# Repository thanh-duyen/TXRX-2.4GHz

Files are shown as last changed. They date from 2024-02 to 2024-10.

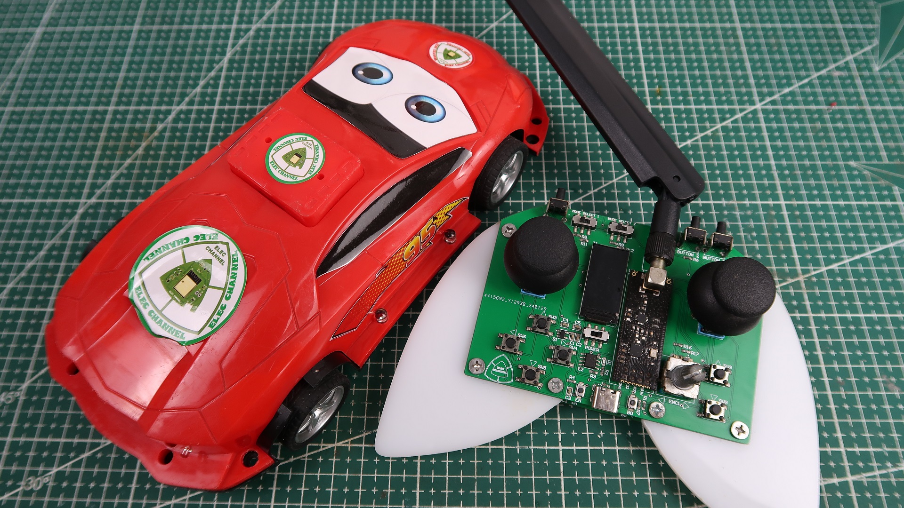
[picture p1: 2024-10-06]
RX_V3_Image_1.JPG

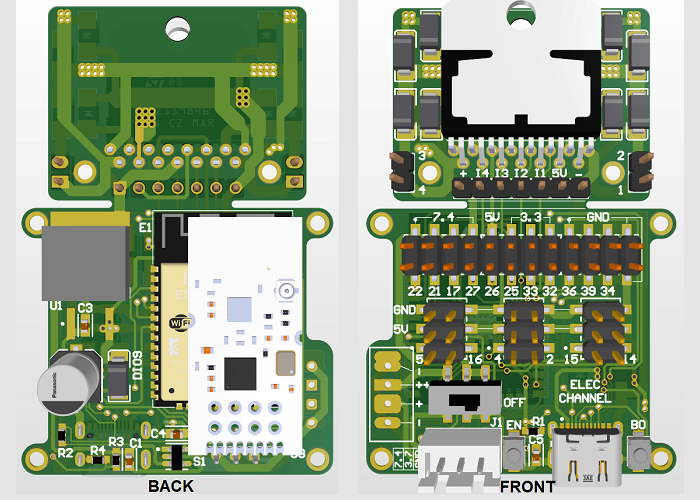
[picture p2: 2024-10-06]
RX_V3_Image_2.png

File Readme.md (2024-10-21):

The reciver for testing is reused from here: https://www.youtube.com/watch?v=fhfw287tRes&t=444s
List of components for TX circuit:
1. Button 3x4mm 2 Pins x2
2. 18650 holder smd x1
3. Button FP-1825027-8-MFG x3
4. Capacitor 0.1uF 0603 x3
5. Capacitor 10uF 0603 x2
6. LED 0603 x1
7. ESP32_WROOM x1
8. ENCODER 24 PPR x1
9. USB Type-C 12 Pins x1
10. JoyStick PS5 x2
11. Switch 6 Pins SMD x3
12. Resistor 100K 0603 x10
13. Resistor 1K 0603 x1
14. Resistor 1K2 0603 x1
15. Resistor 47K 0603 x1
16. Resistor 10K 0603 x1
17. SPX3819M5-L-3-3 x2
18. Button 6x6x6mm 4 Pins x6
19. TFT SPI 13 Pins 80x160 x1
20. nRF24l01 + PA + LNA DIG x1
21. TP4056 x1

List of components for RX circuit version 1:
1. Capacitor 0603 0.1uF x6
2. FP-TAJC-MFG 100uF x1
3. FP-FKD8-MFG 330uF x1
4. LED 0603 x8
5. Diode 1N5819HW x1
6. BUTTON 3x4mm 2 Pin x1
7. USB Type-C 12 Pins x1
8. Inductor 100uH x1
9. Resistor 0603 2K2 x6
10. Resistor 0603 1K x2
11. Resistor 0603 1K2 x1
12. Resistor 0805 180 x1
13. Resistor 0805 0.33 x1
14. Resistor 0603 47K x1
15. Resistor 0603 15K x1
16. Resistor 0603 10k x1
17. SPX3819M5-L-3-3 x1
18. MSS-22D18G2 SWITCH x1
19. TQFP32 ATmega328-AU x1
20. MC34063ACD-TR x1
21. NRF24L01 + PA + LNA SMD x1
22. TP4056 x1
23. Crytal 16MHz 3 Pins x1
24. Led 3mm White x2, Red x2
List of accessories used for RX circuit:
1. Ball-bearings 11.5x10x4(thickness)x3(shaft)mm x2
2. Rubber wheels 18x8x2mm x4
3. Aluminum tube 3(Outer diameter)x2mm
4. Steel/zinc bar 1mm
5. Screw M2, M1.2
6. Servo SG90 360 degree x1
7. 1.5g Micro Linear Servo x1

Note for RX Version 1: The PCB that I designed for using boost to 5V, but the current was not enough to operate, so I removed the ic boost and jumped the direct battery to 5V signal.

For RX version 3, you can get all source here: https://www.pcbway.com/project/shareproject/2_4GHz_receiver_circuit_using_ESP32_nRF24L01_with_IC_motor_controller_L298N_dc1f96e2.html

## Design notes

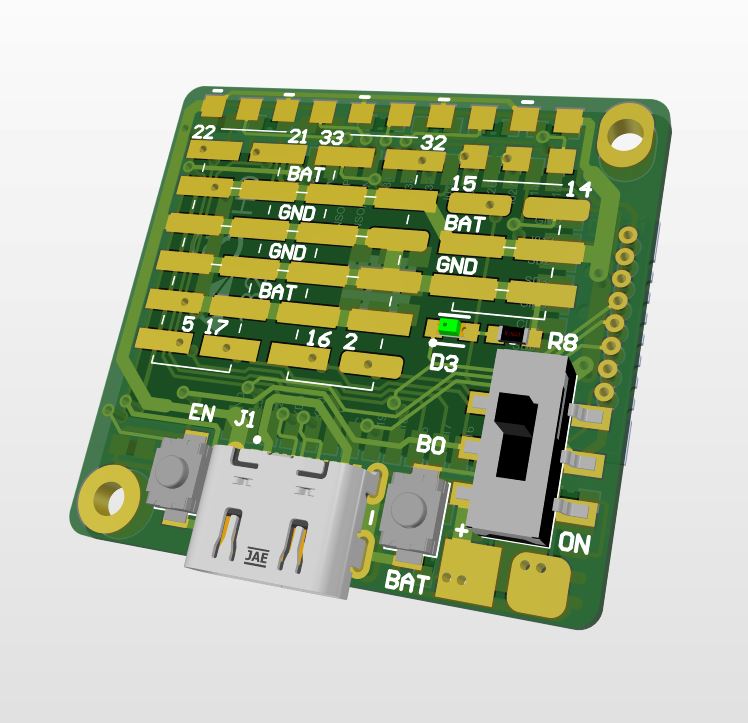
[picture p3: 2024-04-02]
RX_V2_Image_2.JPG

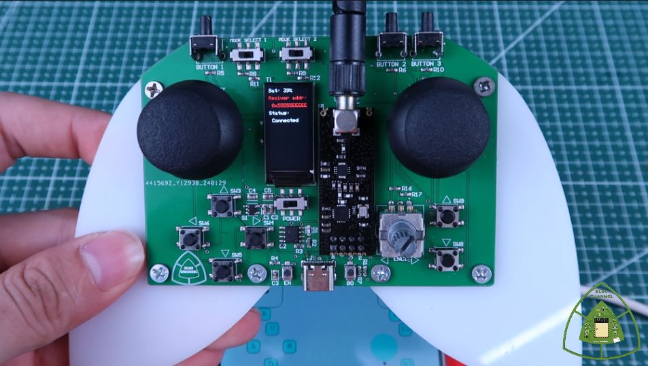
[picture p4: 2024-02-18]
TX_Image.JPG

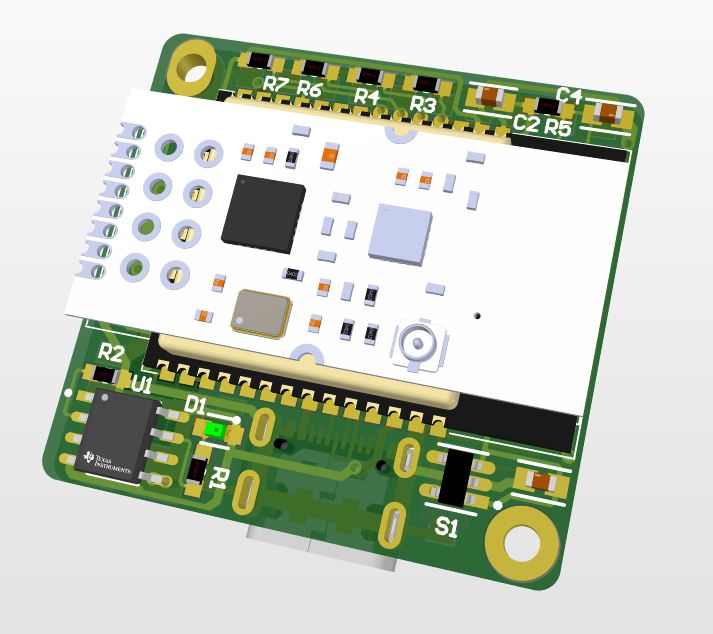
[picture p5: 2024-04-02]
RX_V2_Image_3.JPG

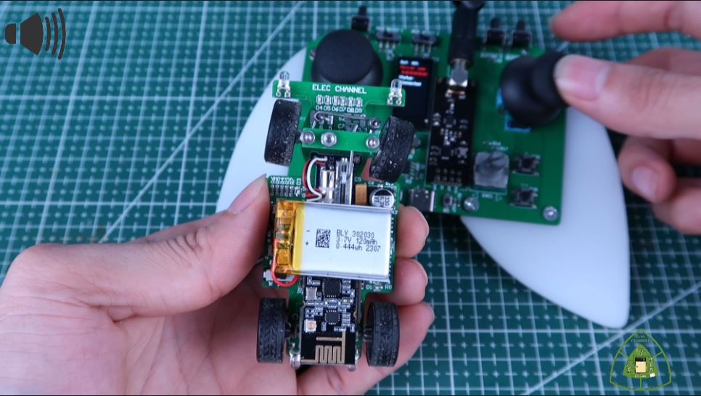
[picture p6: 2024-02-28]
RX_V1_Image.JPG

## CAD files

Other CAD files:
accessory.dwg

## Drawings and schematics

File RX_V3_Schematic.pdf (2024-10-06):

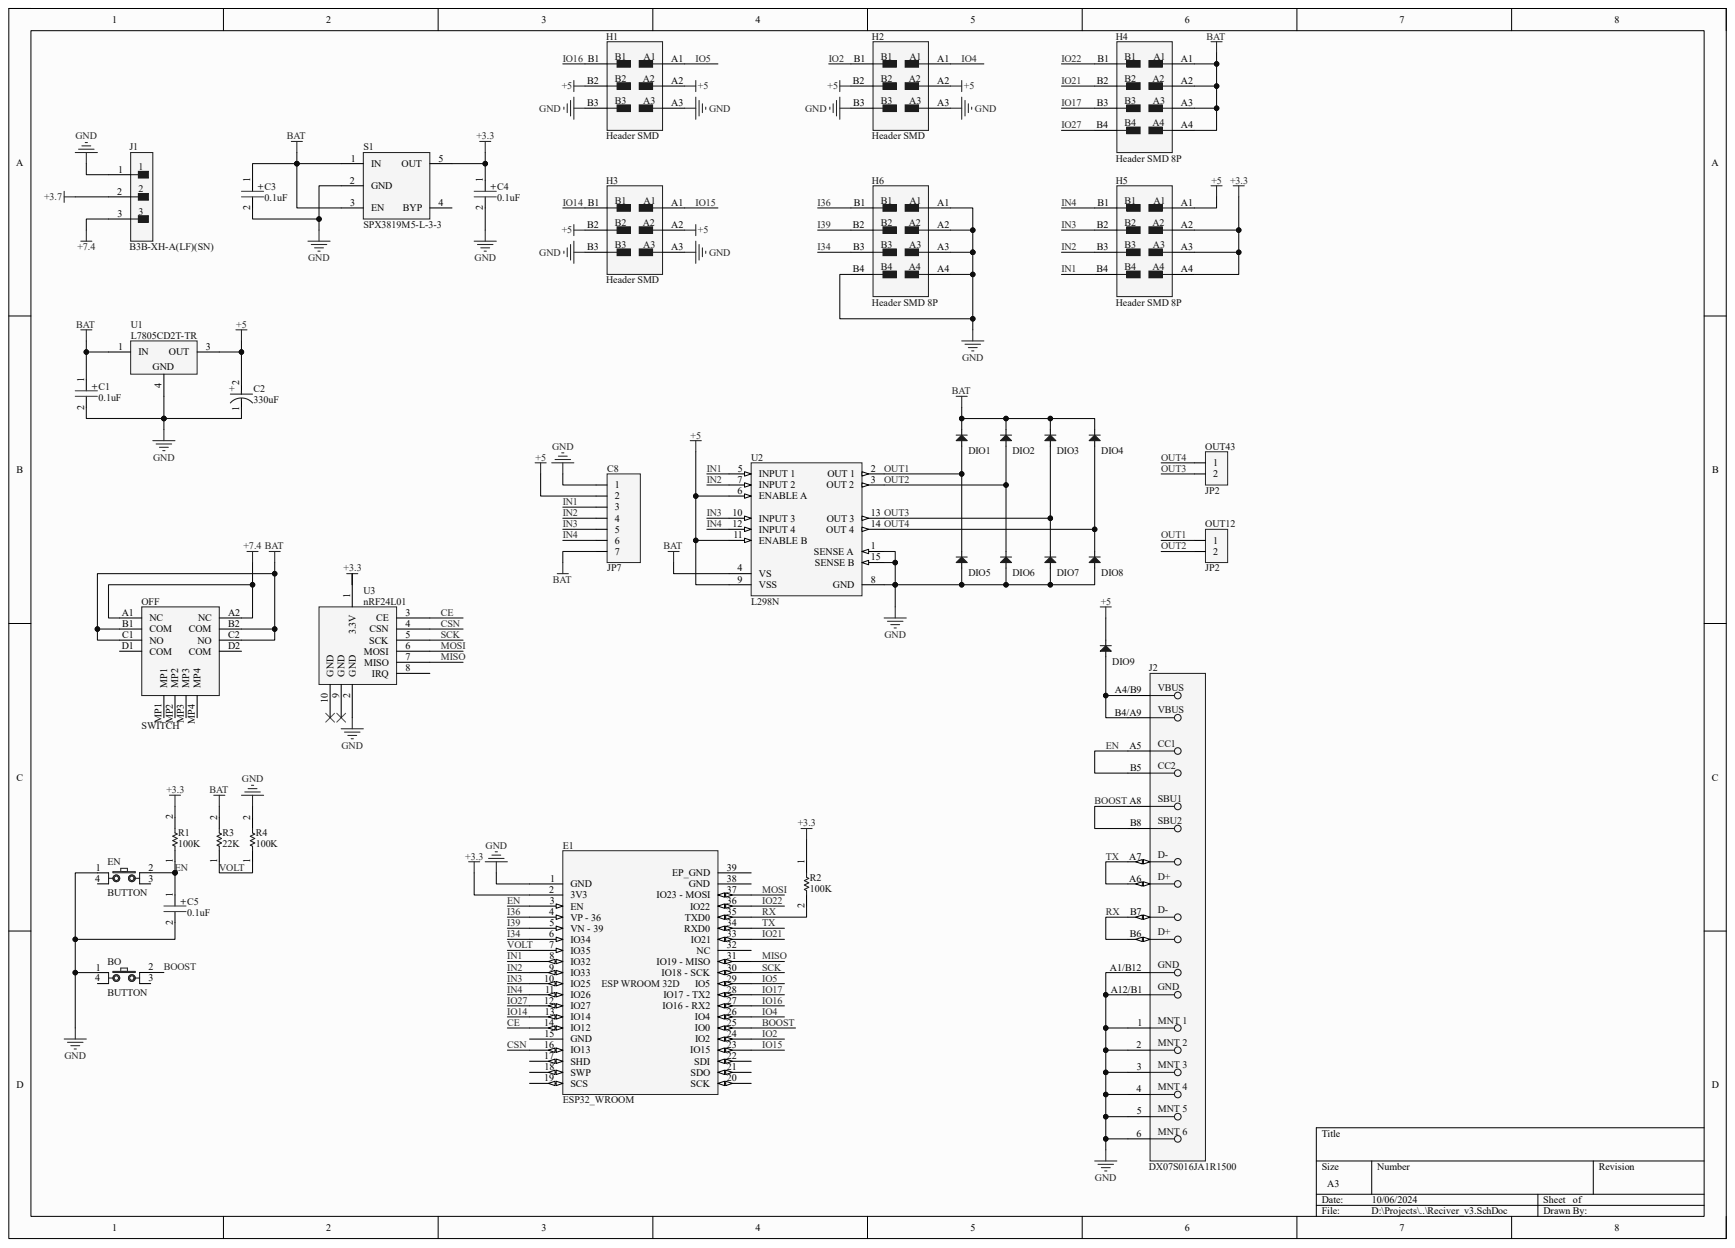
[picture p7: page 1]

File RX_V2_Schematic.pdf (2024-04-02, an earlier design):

+5M 2 1

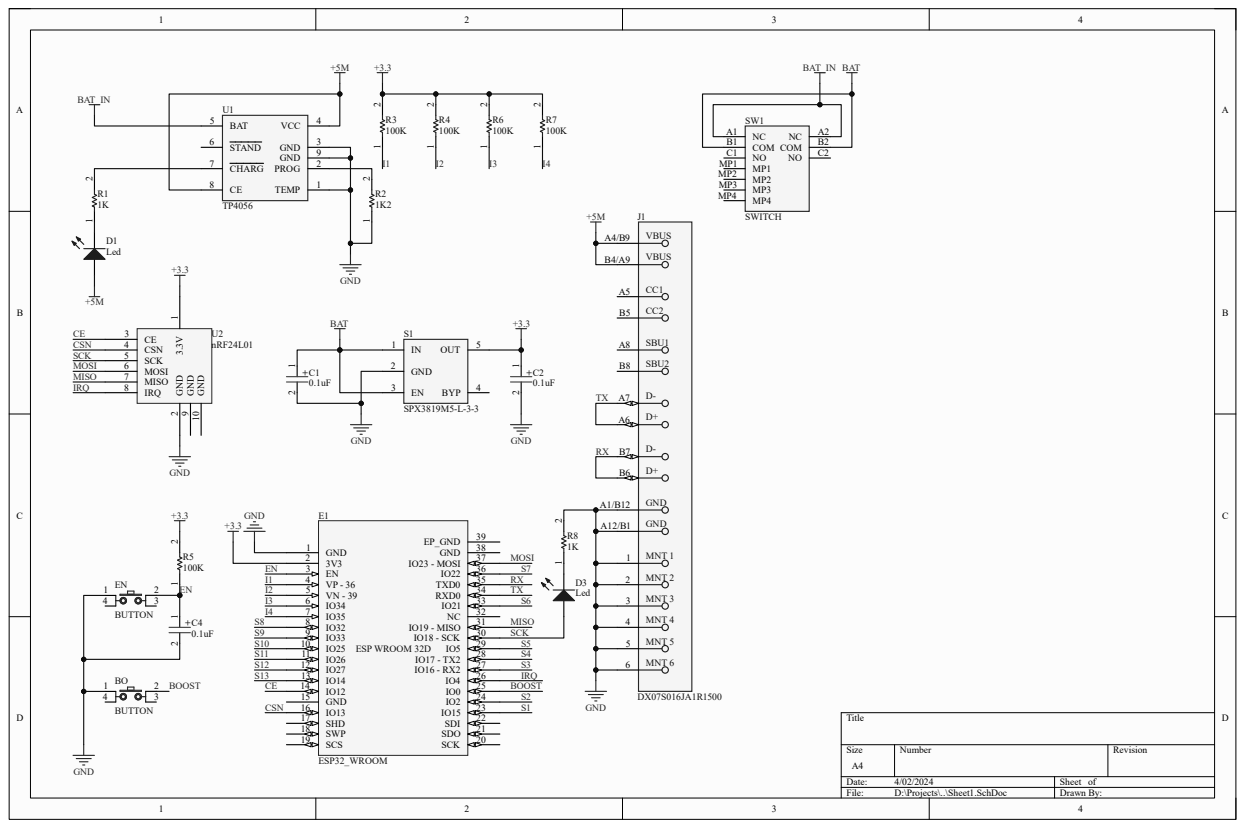
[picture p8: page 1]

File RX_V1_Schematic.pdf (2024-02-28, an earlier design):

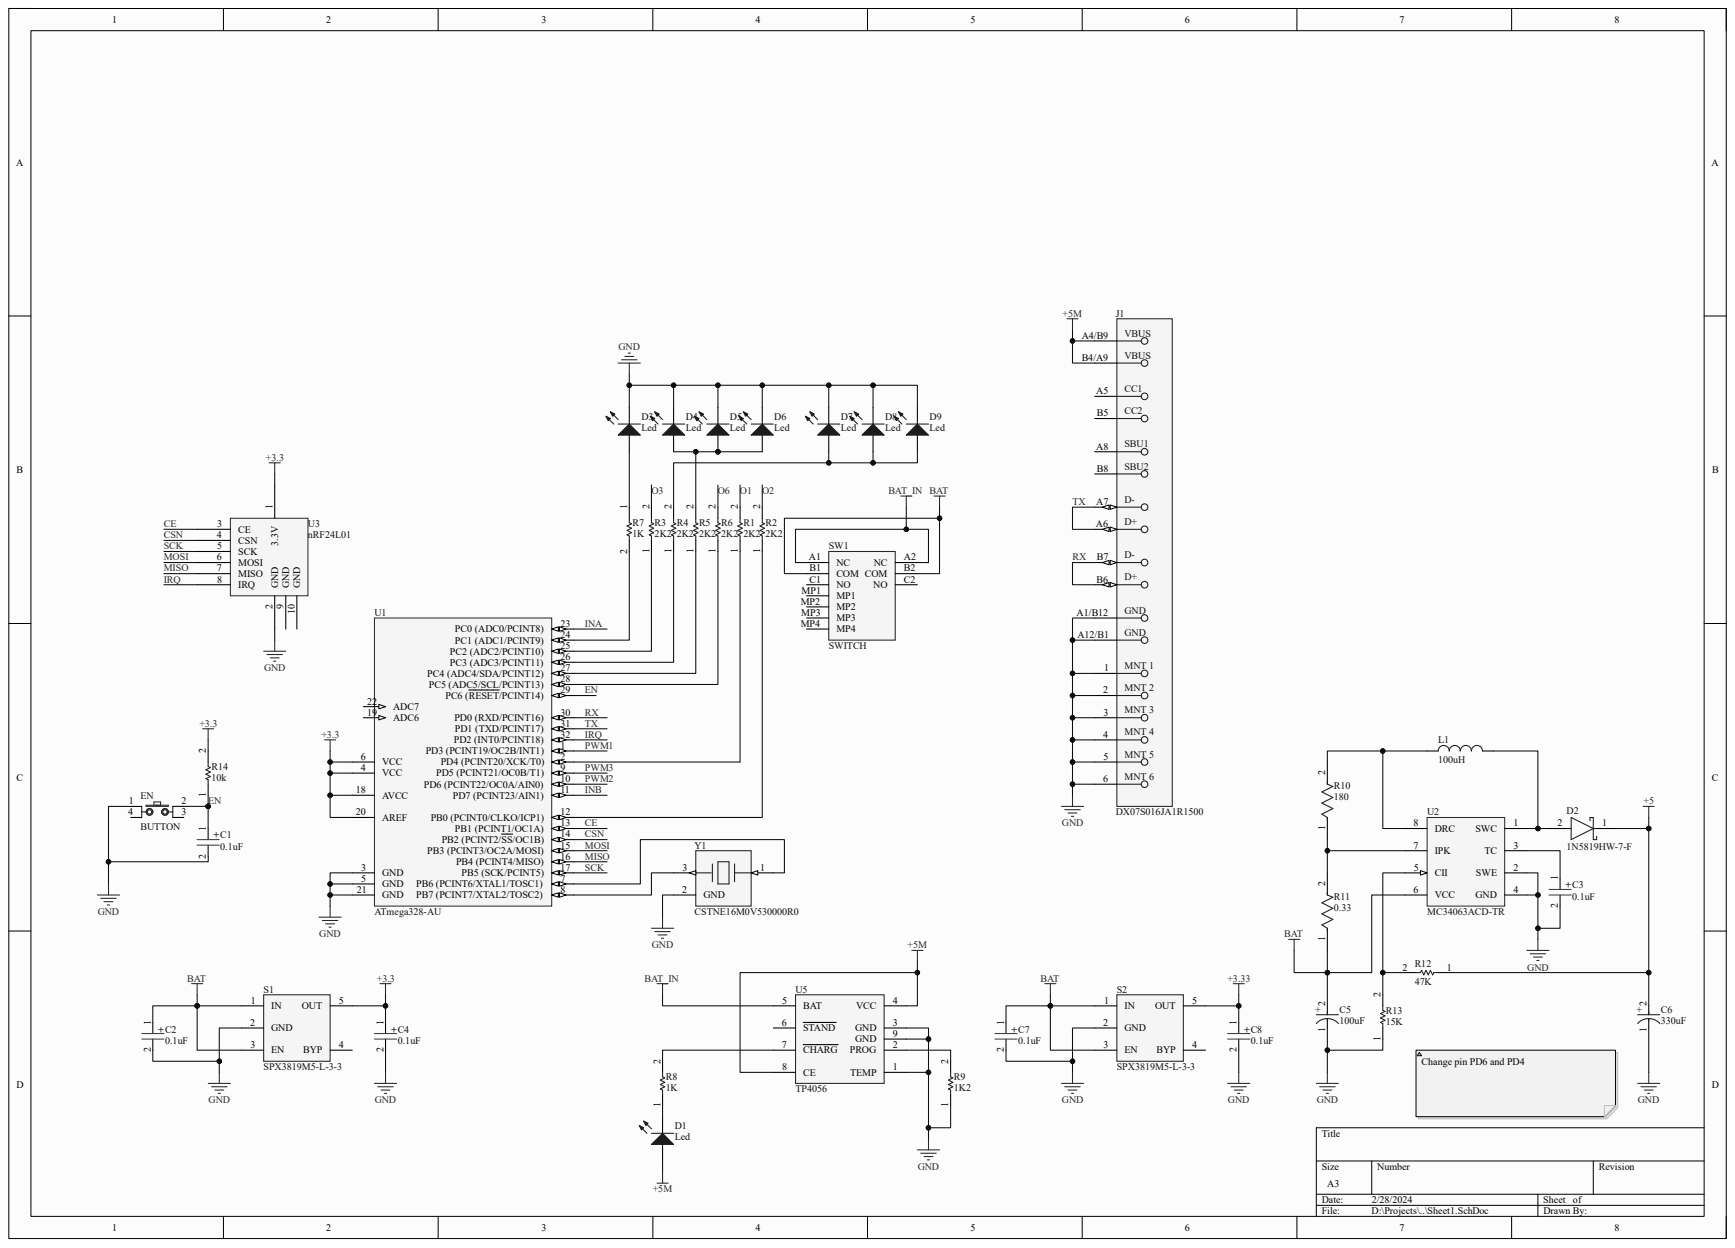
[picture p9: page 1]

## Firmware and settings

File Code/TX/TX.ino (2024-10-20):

#include "data.h"

Adafruit_ST7735 tft = Adafruit_ST7735(CS_LCD_PIN, DC_LCD_PIN, RST_LCD_PIN);
RF24 radio(CE_PIN, CSN_PIN);

void read_battery(bool trigger = false){
  static uint32_t time_readBattery = 0;
  if(trigger) time_readBattery = millis();
  if (time_readBattery > millis())
    return;
  time_readBattery = millis() + 2*MINUTE;
  float volt = read_adc(VOLT_PIN,5)*7.25/4095;
  tft.setCursor(0,0);
  tft.setTextColor(ST77XX_WHITE,ST77XX_BLACK);
  tft.fillRect(0,0,40,15,ST77XX_BLACK);
  
  uint8_t percent = (volt-3.2)*100;
  if(last_batPercent > percent)
    last_batPercent = percent;
  tft.print("Bat: "+String(last_batPercent)+"%");
}
void print_info(){
  String tmp = "";
  for(uint8_t j = 0; j < 5; j++){
    if(EEPROM.read(addnRF_index*5+1+j) < 0x10) tmp += "0";
      tmp += String(EEPROM.read(addnRF_index*5+1+j),HEX);
  }
  tmp.toUpperCase();
  tmp.toCharArray(addnRF_value[addnRF_index],11);
  
  tft.setCursor(0,15);
  tft.setTextColor(ST77XX_RED,ST77XX_BLACK);
  tft.print("ReciverAddr: ");
  tft.setCursor(6,30);
  tft.print("0x"+String(addnRF_value[addnRF_index]));
  tft.setCursor(0,45);
  tft.print("ReciverBa:Unk");
}
void merge_rfdata(sData *data, char *output){
  /* byte 0                      |byte 1  |byte 2  |byte 3  |byte 4  |byte 5       byte 6
   * 0       |12345 |6   |7      |01234567|01234567|01234567|01234567|0123    |456701234567
   * 0       |12345 |6   |7      |89012345|67890123|45678901|01234567|8901    |234567890123
   * is valid|en_pos|mode|bat_req|joys_LX |joys_LY |joys_RX |joys_RY |dir_joys|button[0:10]
   */
  output[0] = 0x1; // is valid to 1
  output[0] = (char)output[0] | (data->encoder_postion << 1);
  if(data->mode_sel1 == 1)
    output[0] = (char)output[0] | (1<<6);
  if(data->batter_request)
    output[0] = (char)output[0] | (1<<7);
  
  output[5] = '\0';
  for(uint8_t i = 0; i < JOYSTICK_NUM; i++){
    output[i+1] = (char)abs(data->joys[i]) & 0xFF;
    if(data->joys[i] >= 0){
      output[5] = (char)output[5] | (1<<i);
    }
  }
  
  for(uint8_t i = 4; i < 8; i++){
    if(data->button[i-4] == 1){
      output[5] = (char)output[5] | (1 << i);
    }
  }
  output[6] = '\0';
  for(uint8_t i = 0; i < 8; i++){
    if(data->button[i+4] == 1){
      output[6] = (char)output[6] | (1 << i);
    }
  }
  output[7] = '\0';
}
void send_rfData(bool is_reset = false){
  /*
   * Input not change -> send every 50ms
   * Input change -> min delay 10ms
   */
  static uint32_t time_run = 0;
  static int32_t times_check = 0;
  static bool is_connected = false;
  static bool last_status = false;
  if(is_reset){
    times_check = 0;
    is_connected = false;
    last_status = false;
    tft.setTextColor(ST77XX_WHITE,ST77XX_BLACK);
    tft.fillRect(0,75,80,15,ST77XX_BLACK);
    tft.setCursor(0,60); tft.print("Status:");
    tft.setCursor(6,75); tft.print("UnConnect");
    return;
  }
  if(!is_nRF_ok)
    return;
  if(time_run > millis())
    return;
  time_run = millis() + fresh_time;
  char text[9] = {NULL};
  merge_rfdata(&rfdata, text);
  if(radio.write(&text, sizeof(text))){
    if((text[0] >> 7) & 0x1){
      radio.startListening();
      rfdata.batter_request = 0;
      uint32_t timeout = millis() + fresh_time;
      String str = "Unk";
      while(millis() < timeout){
        if(radio.available()){
          char text[32] = "";
          radio.read(&text, sizeof(text));
          str = String(text);
          uint8_t bat = str.toInt();
          if(bat < 100)
            str = add_zero(bat,2) + "%";
          else
            str = String(bat);
        }
      }
      tft.setTextColor(ST77XX_RED,ST77XX_BLACK);
      tft.setCursor(60,45);
      tft.print(str);
      radio.stopListening();
    }
    if(is_connected == false) times_check = 0;
    is_connected = true;
    if(++times_check >= 20){
      if(last_status == false){
        tft.setTextColor(ST77XX_WHITE,ST77XX_BLACK);
        tft.fillRect(0,75,80,15,ST77XX_BLACK);
        tft.setCursor(6,75); tft.print("Connected");
        last_status = true;
      }
    }
  }
  else{
    if(is_connected == true) times_check = 0;
    is_connected = false;
    if(++times_check >= 5){
      if(last_status == true){
        tft.setTextColor(ST77XX_WHITE,ST77XX_BLACK);
        tft.fillRect(0,75,80,15,ST77XX_BLACK);
        tft.setCursor(6,75); tft.print("UnConnect");
        last_status = false;
      }
    }
  }
}
String send_rfMesage(String data, eComand cmd, int16_t times, uint32_t timeout = 2000){
  /* byte 0               |byte 1 to byte 31
   * 0        |12345  |67 |
   * must be 0|mes_len|cmd|data
   */
  char text[32] = "";
  char first_byte = (char)(data.length() << 1) | (int)cmd << 6;
  data = (String)first_byte + data;
  if(data.length() >= 32)
    data.toCharArray(text,32);
  else 
    data.toCharArray(text,data.length()+1);
  bool is_ok = false;
  while(--times >= 0){
    if(radio.write(&text, sizeof(text))){
      if(cmd != emGetCmd)
        return "OK";
      radio.startListening();
      timeout = millis() + timeout;
      while(millis() < timeout){
        if(radio.available()){
          radio.read(&text, sizeof(text));
          radio.stopListening();
          return String(text);
        }
      }
    }
  }
  radio.stopListening();
  return "";
}
void print_display(ePage page){
  if(page == emSetting){
    cursor_x = 60;
    cursor_y = 15+0*15+10;
    cursor_width = 17;
    /* base_postion turn_value is_reserve */
    String data_str = send_rfMesage("$A",emGetCmd,1,1000);
    int32_t data_int[3] = {-1, -1, -1};
    uint8_t i = 0, j = 0;
    String buff_str = "";
    while(i < data_str.length() && i < 32 && j < 3){
      if(data_str.charAt(i) != ' '){
        buff_str += data_str.charAt(i);
      }
      else{
        data_int[j++] = buff_str.toInt();
        buff_str = "";
      }
      i++;
    }
    tft.fillScreen(ST77XX_BLACK);
    tft.setTextColor(ST77XX_WHITE,ST77XX_BLACK);
    tft.setCursor(0,0);
    tft.print("ReciverSettin");
    tft.setTextColor(ST77XX_RED,ST77XX_BLACK);
    tft.setCursor(6,15*1);
    if(data_int[0] != -1){
      data_setting.base_postion = data_int[0];
      if(data_setting.base_postion > 999) data_setting.base_postion = 999;
      tft.print("BasePos :" + add_zero(data_setting.base_postion,3));
    }
    else{
      data_setting.base_postion = ERROR_VALUE;
      tft.print("BasePos :Err");
    }
    tft.setCursor(6,15*2);
    if(data_int[1] != -1){
      data_setting.turn_value = data_int[1];
      if(data_setting.turn_value > 999) data_setting.turn_value = 999;
      tft.print("TurnVal :" + add_zero(data_setting.turn_value,3));
    }
    else{
      data_setting.turn_value = ERROR_VALUE;
      tft.print("TurnVal :Err");
    }
    tft.setCursor(6,15*3);
    if(data_int[2] != -1){
      data_setting.is_reserve = data_int[2];
      if(data_setting.is_reserve > 1) data_setting.is_reserve = 1;
      tft.print("Reserve :" + String(data_setting.is_reserve ? "On ":"Off"));
    }
    else{
      data_setting.turn_value = ERROR_VALUE;
      tft.print("Reserve :Err");
    }

    tft.setTextColor(ST77XX_WHITE,ST77XX_BLACK);
    tft.setCursor(0,15*4);
    tft.print("SenderSetting");
    tft.setTextColor(ST77XX_RED,ST77XX_BLACK);
    tft.setCursor(6,15*5);
    tft.print("Fresh :" + add_zero(fresh_time,3) + "ms");
    tft.setCursor(6,15*6);
    tft.print("Rate  :" + String(data_rate + 1) + "MBPS");
    tft.setTextColor(ST77XX_WHITE,ST77XX_BLACK);
    tft.setCursor(0,cursor_y - 10);
    tft.print(">");
    tft.drawLine(cursor_x,cursor_y,cursor_x+cursor_width,cursor_y,ST77XX_WHITE);
    tft.drawLine(cursor_x,cursor_y+1,cursor_x+cursor_width,cursor_y+1,ST77XX_WHITE);
  }
  else if(page == emSelector){
    cursor_x = 18;
    cursor_y = 15 + addnRF_index*15+10;
    cursor_width = 5;
    tft.fillScreen(ST77XX_BLACK);
    tft.setCursor(0,0);
    tft.setTextColor(ST77XX_WHITE,ST77XX_BLACK);
    tft.print("ReciverSelect");
    tft.setTextColor(ST77XX_RED,ST77XX_BLACK);
    for(uint8_t i = 0; i < 9; i++){
      tft.setCursor(0,15+i*15);
      String tmp = "";
      for(uint8_t j = 0; j < 5; j++){
        if(EEPROM.read(i*5+1+j) < 0x10) tmp += "0";
        tmp += String(EEPROM.read(i*5+1+j),HEX);
      }
      tmp.toUpperCase();
      tmp.toCharArray(addnRF_value[i],11);
      if(addnRF_index == i){
        tft.setTextColor(ST77XX_WHITE,ST77XX_BLACK);
        tft.print(">");
        tft.setTextColor(ST77XX_RED,ST77XX_BLACK);
        tft.print(String(i+1)+":"+tmp);
      }
      else tft.print(" "+String(i+1)+":"+tmp);
    }
    tft.drawLine(cursor_x,cursor_y,cursor_x+cursor_width,cursor_y,ST77XX_WHITE);
    tft.drawLine(cursor_x,cursor_y+1,cursor_x+cursor_width,cursor_y+1,ST77XX_WHITE);
  }
}
void read_button(){
  for(uint8_t i = 0; i < ROW_OUTPUT_NUM; i++)
    digitalWrite(ROW_OUTPUT_PIN[i],LOW);
  digitalWrite(ROW_OUTPUT_PIN[row_output],HIGH);
  for(uint8_t i = 0; i < COL_INPUT_NUM; i++){
    uint8_t times = 0;
    while(times < TIMES_JUDGEMENT_BUTTON && digitalRead(COL_INPUT_PIN[i]) != button_status[row_output][i]){
      times++;
      delayMicroseconds(200);
    }
    if(times >= TIMES_JUDGEMENT_BUTTON){
      button_status[row_output][i] = !button_status[row_output][i];
      rfdata.button[row_output*COL_INPUT_NUM+i] = button_status[row_output][i];
      if(page != emHome && button_status[row_output][i] == 1){
        uint8_t button = row_output*COL_INPUT_NUM+i;
        if(button == 1 || button == 3 || button == 4 || button == 5){
          uint16_t _cursor_x = cursor_x, _cursor_y = cursor_y;
          uint8_t old_width = cursor_width;
          if(page == emSelector){
            uint8_t _addnRF_index = addnRF_index;
            if(button == 1 && addnRF_index > 0){ // U
              addnRF_index--;
              cursor_y = 15 + addnRF_index*15+10;
            }
            else if(button == 4 && addnRF_index < 8){ // D
              addnRF_index++;
              cursor_y = 15 + addnRF_index*15+10;
            }
            else if(button == 3 && cursor_x < 72){ // R
              cursor_x = cursor_x + 6;
            }
            else if(button == 5 && cursor_x > 18){ // L
              cursor_x = cursor_x - 6;
            }
            tft.setTextColor(ST77XX_WHITE,ST77XX_BLACK);
            tft.setCursor(0,15+_addnRF_index*15); tft.print(" ");
            tft.setCursor(0,15+addnRF_index*15); tft.print(">");
          }
          else{
            uint8_t cur_index = (cursor_y-15-10)/15;
            uint8_t old_index = cur_index;
            if(button == 1){ // U
              if(cur_index == 4){
                cursor_x = 60;
                cursor_width = 17;
                cur_index -= 2;
                cursor_y -= 30;
              }
              else if(cur_index > 0){
                cur_index--;
                cursor_y -= 15;
                if(cur_index == 3){
                  cursor_x = 6*8;
                  cursor_width = 5;
                }
              }
            }
            else if(button == 4){ // D
              if(cur_index == 2){
                cur_index += 2;
                cursor_y += 30;
                cursor_x = 6*8;
                cursor_width = 5;
              }
              else if(cur_index < 5){
                cur_index++;
                cursor_y += 15;
                if(cur_index == 5) cursor_x = 6*8;
              }
            }
            else if(cur_index == 4){
              if(button == 3 && cursor_x < 60){ // R
                cursor_x = cursor_x + 6;
              }
              else if(button == 5 && cursor_x > 42){ // L
                cursor_x = cursor_x - 6;
              }
            }
            tft.setTextColor(ST77XX_WHITE,ST77XX_BLACK);
            tft.setCursor(0,15+old_index*15); tft.print(" ");
            tft.setCursor(0,15+cur_index*15); tft.print(">");
          }
          tft.drawLine(_cursor_x,_cursor_y,_cursor_x+old_width,_cursor_y,ST77XX_BLACK);
          tft.drawLine(_cursor_x,_cursor_y+1,_cursor_x+old_width,_cursor_y+1,ST77XX_BLACK);
          tft.drawLine(cursor_x,cursor_y,cursor_x+cursor_width,cursor_y,ST77XX_WHITE);
          tft.drawLine(cursor_x,cursor_y+1,cursor_x+cursor_width,cursor_y+1,ST77XX_WHITE);
        }
        else if(button == 7 || button == 8){ // U2 || D2
          int8_t value = 1;
          if(button == 8) value = -1; // D2
          if(page == emSelector){
            addnRF_value[addnRF_index][(cursor_x-18)/6] = (int)addnRF_value[addnRF_index][(cursor_x-18)/6] + value;
            if(addnRF_value[addnRF_index][(cursor_x-18)/6] == '@') addnRF_value[addnRF_index][(cursor_x-18)/6] = '9';
            else if(addnRF_value[addnRF_index][(cursor_x-18)/6] == '/') addnRF_value[addnRF_index][(cursor_x-18)/6] = 'F';
            else if(addnRF_value[addnRF_index][(cursor_x-18)/6] == ':') addnRF_value[addnRF_index][(cursor_x-18)/6] = 'A';
            else if(addnRF_value[addnRF_index][(cursor_x-18)/6] == 'G') addnRF_value[addnRF_index][(cursor_x-18)/6] = '0';
            addnRF_value[addnRF_index][10] = '\0';
            tft.setCursor(0,15+addnRF_index*15);
            tft.setTextColor(ST77XX_WHITE,ST77XX_BLACK);
            tft.print(">");
            tft.setTextColor(ST77XX_RED,ST77XX_BLACK);
            tft.print(String(addnRF_index+1)+":"+String(addnRF_value[addnRF_index]));
          }
          else{
            if(cursor_y == 1*15+10){
              if(data_setting.base_postion != ERROR_VALUE){
                data_setting.base_postion += value;
                tft.setTextColor(ST77XX_RED,ST77XX_BLACK);
                tft.setCursor(6,15*1);
                if(send_rfMesage("#0" + String(data_setting.base_postion),emSetCmd,1) != "OK"){
                  data_setting.base_postion -= value;
                  delay(100);
                }
                tft.setCursor(6,15*1);
                tft.print("BasePos :" + add_zero(data_setting.base_postion,3));
              }
            }
            else if(cursor_y == 2*15+10){
              if(data_setting.turn_value != ERROR_VALUE){
                data_setting.turn_value += value;
                tft.setTextColor(ST77XX_RED,ST77XX_BLACK);
                tft.setCursor(6,15*2);
                if(send_rfMesage("#1" + String(data_setting.turn_value),emSetCmd,1) != "OK"){
                  data_setting.turn_value -= value;
                  delay(100);
                }
                tft.setCursor(6,15*2);
                tft.print("TurnVal :" + add_zero(data_setting.turn_value,3));
              }
            }
            else if(cursor_y == 3*15+10){
              if(data_setting.is_reserve != ERROR_VALUE){
                data_setting.is_reserve += value;
                if(data_setting.is_reserve == 1 || data_setting.is_reserve == 0){
                  tft.setTextColor(ST77XX_RED,ST77XX_BLACK);
                  tft.setCursor(6,15*3);
                  if(send_rfMesage("#2" + String(data_setting.is_reserve),emSetCmd,1) != "OK"){
                    data_setting.is_reserve -= value;
                    delay(100);
                  }
                  tft.setCursor(6,15*3);
                  tft.print("Reserve :" + String(data_setting.is_reserve ? "On ":"Off"));
                }
                else{
                  data_setting.is_reserve -= value;
                }
              }
            }
            else if(cursor_y == 5*15+10){
              if((cursor_x-48)/6 == 0)
                fresh_time = fresh_time + value*100;
              else if((cursor_x-48)/6 == 1)
                fresh_time = fresh_time + value*10;
              else
                fresh_time = fresh_time + value;
              if(fresh_time > 999) fresh_time = 999;
              else if(fresh_time < 10) fresh_time = 10;
              tft.setTextColor(ST77XX_RED,ST77XX_BLACK);
              tft.setCursor(6,15*4);
              tft.print("Fresh :" + add_zero(fresh_time,3) + "ms");
            }
            else if(cursor_y == 6*15+10){
              data_rate += value;
              if(data_rate > 1) data_rate = 1;
              else if(data_rate < 0) data_rate = 0;
              tft.setTextColor(ST77XX_RED,ST77XX_BLACK);
              tft.setCursor(6,15*5);
              tft.print("Rate  :" + String(data_rate + 1) + "MBPS");
            }
          }
        }
        else if(button == 9){
          if(page == emSetting){
            page = emSelector;
            print_display(page);
          }
          else{
            page = emSetting;
            print_display(page);
          }
        }
      }
    }
  }
  if(++row_output >= ROW_OUTPUT_NUM){
    row_output = 0;
  }
}
void read_switch(){
  static uint32_t time_run = 0;
  static uint8_t times = 0;
  if(time_run > millis())
    return;
  time_run = millis()+25;
  uint16_t average = analogRead(MODE_SELECT_PIN);
  for(uint8_t i = 0; i < 5; i++){
    average = (analogRead(MODE_SELECT_PIN)+average)/2;
  }
  bool sel_1 = 0, sel_2 = 0;
  if(average > 2550 && average < 2650)
    sel_1 = 1;
  else if(average > 150 && average < 250)
    sel_2 = 1;
  else if(average > 500 && average < 550){
    sel_1 = 1;
    sel_2 = 1;
  }
  if(sel_1 != rfdata.mode_sel1 || sel_2 != rfdata.mode_sel2){
    if(++times >= 20){
      rfdata.mode_sel1 = sel_1;
      rfdata.mode_sel2 = sel_2;
      if(rfdata.mode_sel2 == 1 && page == emHome){
        delay(fresh_time);
        String respond = send_rfMesage("$$",emGetCmd,1,fresh_time);
        if(respond != "KO"){
          page = emSelector;
          print_display(page);
        }
        else{
          tft.setTextColor(ST77XX_YELLOW,ST77XX_BLACK);
          tft.setCursor(0,105); tft.print("Can't setting");
        }
      }
      else if(rfdata.mode_sel2 == 0 && page == emHome){
        tft.fillRect(0,105,80,15,ST77XX_BLACK);
      }
      else if(rfdata.mode_sel2 == 0 && page != emHome){
        char temp[3] = "\0\0";
        for(uint8_t a = 0; a < 9; a++){
          for(uint8_t i = 0, k = 0; i < 10 && k < 5; i++, k++){
            temp[0] = addnRF_value[a][i];
            i++;
            temp[1] = addnRF_value[a][i];
            EEPROM.write(1+a*5+k,strtol(temp, 0, 16));
          }
        }
        EEPROM.write(0,addnRF_index);
        EEPROM.write(50,fresh_time/255);
        EEPROM.write(51,fresh_time%255);
        EEPROM.write(52,data_rate);
        EEPROM.commit();
        uint8_t address[6] = "abcde";
        for(int8_t i = 4; i >= 0; i--){
          address[4-i] = EEPROM.read(1+addnRF_index*5+i);
        }
        radio.setDataRate((rf24_datarate_e)data_rate);
        radio.openWritingPipe(address);
        radio.openReadingPipe(1, address);
        //radio.printDetails();
        page = emHome;
        tft.fillScreen(ST77XX_BLACK);
        print_info();
        read_battery(true);
        send_rfData(true);
      }
    }
  }
  else{
    times = 0;
  }
}
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
void loop(){
  if(millis() >= time_req_bat){
    rfdata.batter_request = 1;
    time_req_bat = millis() + 1*MINUTE;
  }
  if(page == emHome){
    read_joystick();
    send_rfData();
    read_battery();
  }
  read_button();
  read_encoder();
  read_switch();
  read_terminal();
}

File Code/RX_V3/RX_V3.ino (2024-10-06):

#include "data.h"
RF24 radio(CE_PIN, CSN_PIN);
Servo servo;

void read_battery(){
  static uint32_t time_read = 0;
  static uint8_t last_battery = 100;
  if(millis() < time_read)
    return;
  time_read = millis() + 30*SECOND;
  uint16_t average = analogRead(VOLT_PIN);
  for(uint8_t i = 0; i < 5; i++){
    average = (average + analogRead(VOLT_PIN))/2;
  }
  /* Bat: 7.78, readed: 1.82 */
  battery_percent = ((average*3.263/4096)*4.27 - 6.4)/2*100;
  if(battery_percent > last_battery)
    battery_percent = last_battery;
  last_battery = battery_percent;
}
void motor_control(eMotor motor, eDir dir, uint8_t pwm){
  if(motor != emMotor12 && motor != emMotor34)
    return;
  if(dir == emForward){
    digitalWrite(MOTOR_PIN[motor], LOW);
    ledcWrite(motor, pwm);
  }
  else{
    digitalWrite(MOTOR_PIN[motor], pwm ? HIGH:LOW);
    ledcWrite(motor, pwm);
  }
}
bool send_rf(String data, int16_t times){
  radio.stopListening();
  char text[32] = {"\0"};
  data.toCharArray(text,data.length()+1);
  while(--times >= 0){
    if(radio.write(&text, sizeof(text))){
      radio.startListening();
      return true;
    }
  }
  radio.startListening();
  return false;
}
void print_rfdata(){
  Serial.printf("XL=%d\tYL=%d\tXR=%d\tYR=%d\tMode=%d\tButton=%d%d%d%d%d%d%d%d%d%d%d%d\tEncoder=%d\n",
    rfdata.joys_leftX, rfdata.joys_leftY, rfdata.joys_rightX, rfdata.joys_rightY,
    rfdata.mode_sel1, rfdata.button[0], rfdata.button[1], rfdata.button[2], rfdata.button[3], 
    rfdata.button[4], rfdata.button[5], rfdata.button[6], rfdata.button[7], rfdata.button[8], 
    rfdata.button[9], rfdata.button[10], rfdata.button[11], rfdata.encoder_postion);
}
void parse_data(char *data){
  /* byte 0                      |byte 1  |byte 2  |byte 3  |byte 4  |byte 5       |byte 6
   * 0       |12345 |6   |7      |01234567|01234567|01234567|01234567|0123    |456701234567
   * 0       |12345 |6   |7      |89012345|67890123|45678901|01234567|8901    |234567890123
   * is valid|en_pos|mode|bat_req|joys_LX |joys_LY |joys_RX |joys_RY |dir_joys|button[0:10]
   */
  if((int)data[0]  & 0x1 == 0)
    return;
  rfdata.time_lastRecive = millis();
  rfdata.encoder_postion = (((int)data[0] >> 1) & 0x1F);
  rfdata.mode_sel1 = ((int)data[0] >> 6) & 0x1;
  if(((int)data[0] >> 7) & 0x1){
    send_rf(String(battery_percent) + "%", 1);
  }
  rfdata.joys_leftX = (uint8_t)data[1];
  rfdata.joys_leftY = (uint8_t)data[2];
  rfdata.joys_rightX = (uint8_t)data[3];
  rfdata.joys_rightY = (uint8_t)data[4];
  if((((int)data[5] >> 0) & 0x1) == 0) rfdata.joys_leftX *= -1;
  if((((int)data[5] >> 1) & 0x1) == 0) rfdata.joys_leftY *= -1;
  if((((int)data[5] >> 2) & 0x1) == 0) rfdata.joys_rightX *= -1;
  if((((int)data[5] >> 3) & 0x1) == 0) rfdata.joys_rightY *= -1;

  for(uint8_t i = 4; i < 8; i++){
    rfdata.button[i-4] = ((int)data[5] >> i) & 0x1;
  }
  for(uint8_t i = 0; i < 8; i++){
    rfdata.button[i+4] = ((int)data[6] >> i) & 0x1;
  }

  motor_control(emMotor12, rfdata.joys_leftY > 0 ? emForward:emBackward, rfdata.joys_leftY);
  int8_t temp = is_reserve ? 1:-1;
  int16_t value = map(rfdata.joys_rightX,-255,255,base_postion-turn_value*temp,base_postion+turn_value*temp);
  servo.write(value);
//  print_rfdata();
}
void read_nRF(){
  if(radio.available()){
    char text[8] = "";
    radio.read(&text, sizeof(text));
    String str = String(text);
    if(text[0] & 0x1){
      parse_data(text);
    }
    else{
      if(str.indexOf("$") >= 0){ // tx reads parameter
        if(str.indexOf("$A") >= 0){
          String data = String(EEPROM.read(0))+" "+String(EEPROM.read(1))+" "+String(EEPROM.read(2))+" ";
          delay(50); bool is_ok = send_rf(data,10);
        }
        else{
          uint8_t value = uint8_t(str.charAt(str.indexOf("$") + 1))-48;
          value = EEPROM.read(value); delay(50);
          bool is_ok = send_rf(String(value),10);
        }
      }
      else if(str.indexOf("#") >= 0){ // tx sets parameter
        String buff = "";
        uint8_t i = str.indexOf("#") + 2;
        while(i < str.length()){
          buff += str.charAt(i);
          i++;
        }
        EEPROM.write(uint8_t(str.charAt(str.indexOf("#")+1))-48, buff.toInt());
        EEPROM.commit();
        if(str.charAt(str.indexOf("#") + 1) == '0'){
          servo.write(buff.toInt());
          base_postion = buff.toInt();
        }
        else if(str.charAt(str.indexOf("#") + 1) == '1'){
          turn_value = buff.toInt();
        }
        else if(str.charAt(str.indexOf("#") + 1) == '2'){
          is_reserve = buff.toInt();
        }
      }
      else{
        Serial.printf("Recived an unknow command: %s\n", str);
      }
    }
  }
}
void leds_handler(){
  if(millis() >= rfdata.time_lastRecive + 1000){
    if(millis() >= time_blink){
      time_blink = millis() + 200 + is_left_on*800;
      is_left_on = !is_left_on;
      digitalWrite(LEFT_LED_PIN, is_left_on);
      digitalWrite(RIGHT_LED_PIN, is_left_on);
      motor_control(emMotor12, emBackward, 0); // stop motor
      servo.write(base_postion);
    }
  }
  else if(rfdata.mode_sel1 == 1){
    if(millis() >= time_blink){
      is_left_on = !is_left_on;
      if(is_left_on){
        digitalWrite(LEFT_LED_PIN,HIGH);
        digitalWrite(RIGHT_LED_PIN,LOW);
      }
      else{
        digitalWrite(LEFT_LED_PIN,LOW);
        digitalWrite(RIGHT_LED_PIN,HIGH);
      }
      time_blink = millis() + time_delay;
    }
  }
  else {
    digitalWrite(LEFT_LED_PIN, rfdata.button[10]);
    digitalWrite(RIGHT_LED_PIN, rfdata.button[10]);
  }
  
  digitalWrite(FRONT_LED_PIN,rfdata.button[9]);
  digitalWrite(BACK_LED_PIN,rfdata.button[11]);
}
void setup(){
  Serial.begin(115200);
  EEPROM.begin(50);
  if(radio.begin()){
    is_nRF_ok = true;
    Serial.println("nRF is OK!");
    radio.setPayloadSize(32);
    radio.setDataRate(RF24_2MBPS);
    radio.openWritingPipe(0xECECECECEC);
    radio.openReadingPipe(1, 0xECECECECEC);
    radio.setPALevel(RF24_PA_MAX);
    radio.startListening();
  }
  else{
    is_nRF_ok = false;
    Serial.println("nRF is BAD!");
  }
  for(uint8_t i = 0;i < 4; i++){
    pinMode(MOTOR_PIN[i],OUTPUT);
    pinMode(LED_PIN[i],OUTPUT);
  }
  
  base_postion = EEPROM.read(0);
  if(base_postion > 180){
    base_postion = 90;
    EEPROM.write(0, 90);
    EEPROM.commit();
  }
  turn_value = EEPROM.read(1);
  if(turn_value > 90){
    turn_value = 45;
    EEPROM.write(1, 45);
    EEPROM.commit();
  }
  is_reserve = EEPROM.read(2);
  if(is_reserve > 1){
    is_reserve = 1;
    EEPROM.write(2, 1);
    EEPROM.commit();
  }
  servo.attach(SERVO_PIN, 5);
  servo.write(base_postion);
  
  ledcAttachPin(IN1_PIN, emMotor12);
  ledcSetup(emMotor12, 12000, 8);
  ledcWrite(emMotor12, 0);
  ledcAttachPin(IN3_PIN, emMotor34);
  ledcSetup(emMotor34, 12000, 8);
  ledcWrite(emMotor34, 0);
}
void loop(){
  if(is_nRF_ok){
    read_nRF();
  }
  leds_handler();
  read_battery();
}

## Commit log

2024-02-16 Add accessory file
    [accessory.dwg]
2024-10-06 Add image RX_V3, modify schematic for RX_V3
